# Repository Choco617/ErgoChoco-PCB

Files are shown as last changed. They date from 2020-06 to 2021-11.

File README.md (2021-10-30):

# ErgoChoco-PCB
 My first PCB - a de-split split layout taking my favorite design details from the Corne, Kyria, Absolem, and others.

## The name
 I'm an engineer, and true to form I'm bad at naming things. I'd heard the ErgoDox was designed by a user named Dox, and my handle is Choco617, so: ErgoChoco.
 
## Layout explanation:
I love my Corne, but I quickly found that I always orient the halves the same way, making the actual separation and the TRRS cable more of a nuisance, much as I love the concept. So I experimented with angles and settled on 30°. I had also always wondered if I would like more columnar stagger: the Corne seems pretty conservative on that. So after reading the Kyria design log, I took the same approach, made some measurements of my own fingers’ natural resting positions, and discovered they were negligibly different from the Kyria’s, so I lifted those columnar stagger dimensions wholesale. I love the look of the 1.5U thumb keys on the Corne, but I admit it’s always been annoying for keycap compatibility that they prevent me from just getting a Planck set, so I replaced the 1.5U keys with 1U. I set the hands just far enough apart to fit a Pro Micro between them. A cardboard prototype with leftover switches/caps stuffed into it confirmed that was a comfy layout for me (and the all-1U thumb arcs don’t look as bad as I worried they would).

## Design Priorities:

### PCB
- Kailh hotswap sockets (direct soldering not supported: I'm the only intended user, so I can do what I want :P)
- In-switch LED (with Holtites so that it doesn't defeat the purpose of switch hotswap)
- South-facing switches (I like seeing the LEDs right up front)
- Pro Micro. I originally designed this with an onboard MCU, then decided I would rather keep all the complicated stuff on a Pro Micro to keep the PCB simpler/cheaper and allow me to replace the controller if something awful happened. Also, Pro Micro instead of Elite-C just because I already have micro-USB cables. The Pro Micro is socketed anyway, so I can always change later if I feel like it.
- SMD all the things (mostly diodes/resistors). I wanted to see if I could actually solder all of it myself, and I like the idea of keeping everything as small as possible, and technically minimizing EMI.
- Ground plane everywhere. My original Contra was very prone to ESD shocks, so in the original onboard-MCU version of this PCB, I had an ESD protection circuit with a PRTR5V0U2X. Now with a Pro Micro design, the best I can do (I think) is extensive ground planes and connecting the mounting holes to them so the PCB is grounded to the stainless steel case. I'm a mechanical engineer, not an electrical engineer, so I hope this is sufficient.
- Breakout pads for GND/+5V/F4 data pin to allow RGB underglow (inspired by the Contra). Not sure where I would physically fit an RGB strip, since I intentionally designed no gap under the PCB, but it seemed silly not to include this while I was designing the PCB, since I had the pin available.

### Case (dedicated repo: [https://github.com/Choco617/ErgoChoco-case](https://github.com/Choco617/ErgoChoco-case))
- Stainless sandwich/skeleton case. Top and bottom plates have a perimeter of 8mm aluminum standoffs around the edges of the PCB. I've used this in previous boards, and I love the look.
- Bottom plate mechanically supports hotswap sockets from behind. It annoys me that switch-swapping in my sandwich-case Corne requires me to disassemble everything so I can hold the sockets firm when I insert the new switches, so this case is designed so that the bottom plate (through a layer of non-conductive gasket) contacts the sockets. The PCB is bolted to the bottom plate to keep this secure.
- Minimal height. Without resorting to low-profile switches, I want to keep the plate height as low as possible, mainly for aesthetics and comfort reasons, but also because it's mechanically necessary in order to let the bottom plate contact the backs of the hotswap sockets.
- Pro Micro installation on PCB: to minimize height but still keep the Pro Micro under the plate (I don't like them exposed like on the Corne), the PCB has a U-shaped relief at the Pro Micro footprint. The Pro Micro is installed component-side down on the top of the PCB so the USB port hangs down into that relief.
- Case structure as a result of these choices: PCB is bolted to the top of the bottom plate, with a gasket layer (just vaguely compressible rubbery drawer liner, nothing fancy) in between for electrical insulation, then standoffs are bolted to the top of the bottom plate around the PCB, then the top plate is bolted to the standoffs, then switches are inserted.

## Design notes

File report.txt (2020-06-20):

Info: Checking netlist symbol footprint “R6:/5F0DCCB4:Resistor_SMD:R_0805_2012Metric”.
Info: Checking netlist symbol footprint “MX41:/5F185EF9:Choco617_parts:Kailh_socket_MX_PCBmount_LED_1U”.
Info: Checking netlist symbol footprint “MX42:/5F185F0C:Choco617_parts:Kailh_socket_MX_PCBmount_LED_1U”.
Info: Checking netlist symbol footprint “NPNR1:/5F5CF76A:Resistor_SMD:R_0805_2012Metric”.
Info: Checking netlist symbol footprint “Q1:/5F5CD88C:Package_TO_SOT_SMD:SOT-223”.
Info: Checking netlist symbol footprint “R1:/5F0CFD20:Resistor_SMD:R_0805_2012Metric”.
Info: Checking netlist symbol footprint “R2:/5F0D5418:Resistor_SMD:R_0805_2012Metric”.
Info: Checking netlist symbol footprint “R3:/5F0D6D67:Resistor_SMD:R_0805_2012Metric”.
Info: Checking netlist symbol footprint “R4:/5F0D842C:Resistor_SMD:R_0805_2012Metric”.
Info: Checking netlist symbol footprint “R5:/5F0DB2B4:Resistor_SMD:R_0805_2012Metric”.
Info: Checking netlist symbol footprint “MX40:/5F185EE6:Choco617_parts:Kailh_socket_MX_PCBmount_LED_1U”.
Info: Checking netlist symbol footprint “R7:/5F0DE3D1:Resistor_SMD:R_0805_2012Metric”.
Info: Checking netlist symbol footprint “R8:/5F0E0A19:Resistor_SMD:R_0805_2012Metric”.
Info: Checking netlist symbol footprint “R9:/5F0E23BF:Resistor_SMD:R_0805_2012Metric”.
Info: Checking netlist symbol footprint “R10:/5F0E38CD:Resistor_SMD:R_0805_2012Metric”.
Info: Checking netlist symbol footprint “R11:/5F0E53BC:Resistor_SMD:R_0805_2012Metric”.
Info: Checking netlist symbol footprint “R12:/5F0E6AFF:Resistor_SMD:R_0805_2012Metric”.
Info: Checking netlist symbol footprint “R13:/5F13CD72:Resistor_SMD:R_0805_2012Metric”.
Info: Checking netlist symbol footprint “R14:/5F13CD85:Resistor_SMD:R_0805_2012Metric”.
Info: Checking netlist symbol footprint “MX31:/5F163023:Choco617_parts:Kailh_socket_MX_PCBmount_LED_1U”.
Info: Checking netlist symbol footprint “MX23:/5F13CE23:Choco617_parts:Kailh_socket_MX_PCBmount_LED_1U”.
Info: Checking netlist symbol footprint “MX24:/5F13CE36:Choco617_parts:Kailh_socket_MX_PCBmount_LED_1U”.
Info: Checking netlist symbol footprint “MX25:/5F162FB1:Choco617_parts:Kailh_socket_MX_PCBmount_LED_1U”.
Info: Checking netlist symbol footprint “MX26:/5F162FC4:Choco617_parts:Kailh_socket_MX_PCBmount_LED_1U”.
Info: Checking netlist symbol footprint “MX27:/5F162FD7:Choco617_parts:Kailh_socket_MX_PCBmount_LED_1U”.
Info: Checking netlist symbol footprint “MX28:/5F162FEA:Choco617_parts:Kailh_socket_MX_PCBmount_LED_1U”.
Info: Checking netlist symbol footprint “MX29:/5F162FFD:Choco617_parts:Kailh_socket_MX_PCBmount_LED_1U”.
Info: Checking netlist symbol footprint “MX30:/5F163010:Choco617_parts:Kailh_socket_MX_PCBmount_LED_1U”.
Info: Checking netlist symbol footprint “R15:/5F13CD98:Resistor_SMD:R_0805_2012Metric”.
Info: Checking netlist symbol footprint “MX32:/5F163036:Choco617_parts:Kailh_socket_MX_PCBmount_LED_1U”.
Info: Checking netlist symbol footprint “MX33:/5F163049:Choco617_parts:Kailh_socket_MX_PCBmount_LED_1U”.
Info: Checking netlist symbol footprint “MX34:/5F16305C:Choco617_parts:Kailh_socket_MX_PCBmount_LED_1U”.
Info: Checking netlist symbol footprint “MX35:/5F16306F:Choco617_parts:Kailh_socket_MX_PCBmount_LED_1U”.
Info: Checking netlist symbol footprint “MX36:/5F163082:Choco617_parts:Kailh_socket_MX_PCBmount_LED_1U”.
Info: Checking netlist symbol footprint “MX37:/5F185EAD:Choco617_parts:Kailh_socket_MX_PCBmount_LED_1U”.
Info: Checking netlist symbol footprint “MX38:/5F185EC0:Choco617_parts:Kailh_socket_MX_PCBmount_LED_1U”.
Info: Checking netlist symbol footprint “MX39:/5F185ED3:Choco617_parts:Kailh_socket_MX_PCBmount_LED_1U”.
Info: Checking netlist symbol footprint “R42:/5F185F19:Resistor_SMD:R_0805_2012Metric”.
Info: Checking netlist symbol footprint “R34:/5F163069:Resistor_SMD:R_0805_2012Metric”.
Info: Checking netlist symbol footprint “R35:/5F16307C:Resistor_SMD:R_0805_2012Metric”.
Info: Checking netlist symbol footprint “R36:/5F16308F:Resistor_SMD:R_0805_2012Metric”.
Info: Checking netlist symbol footprint “R37:/5F185EBA:Resistor_SMD:R_0805_2012Metric”.
Info: Checking netlist symbol footprint “R38:/5F185ECD:Resistor_SMD:R_0805_2012Metric”.
Info: Checking netlist symbol footprint “R39:/5F185EE0:Resistor_SMD:R_0805_2012Metric”.
Info: Checking netlist symbol footprint “R40:/5F185EF3:Resistor_SMD:R_0805_2012Metric”.
Info: Checking netlist symbol footprint “R41:/5F185F06:Resistor_SMD:R_0805_2012Metric”.
Info: Checking netlist symbol footprint “R33:/5F163056:Resistor_SMD:R_0805_2012Metric”.
Info: Checking netlist symbol footprint “R43:/5EEC55CA:Resistor_SMD:R_0805_2012Metric”.
Info: Checking netlist symbol footprint “R44:/5F5EB1F7:Resistor_SMD:R_0805_2012Metric”.
Info: Checking netlist symbol footprint “R45:/5F601D9F:Resistor_SMD:R_0805_2012Metric”.
Info: Checking netlist symbol footprint “R46:/5EE95709:Resistor_SMD:R_0805_2012Metric”.
Info: Checking netlist symbol footprint “SW1:/5EEBD541:random-keyboard-parts:SKQG-1155865”.
Info: Checking netlist symbol footprint “U1:/5EE90A1B:Package_QFP:TQFP-44_10x10mm_P0.8mm”.
Info: Checking netlist symbol footprint “U2:/5F5EB805:random-keyboard-parts:SOT143B”.
Info: Checking netlist symbol footprint “Y1:/5EEB2728:Crystal:Crystal_SMD_3225-4Pin_3.2x2.5mm”.
Info: Checking netlist symbol footprint “R24:/5F13CE43:Resistor_SMD:R_0805_2012Metric”.
Info: Checking netlist symbol footprint “R16:/5F13CDAB:Resistor_SMD:R_0805_2012Metric”.
Info: Checking netlist symbol footprint “R17:/5F13CDBE:Resistor_SMD:R_0805_2012Metric”.
Info: Checking netlist symbol footprint “R18:/5F13CDD1:Resistor_SMD:R_0805_2012Metric”.
Info: Checking netlist symbol footprint “R19:/5F13CDE4:Resistor_SMD:R_0805_2012Metric”.
Info: Checking netlist symbol footprint “R20:/5F13CDF7:Resistor_SMD:R_0805_2012Metric”.
Info: Checking netlist symbol footprint “R21:/5F13CE0A:Resistor_SMD:R_0805_2012Metric”.
Info: Checking netlist symbol footprint “R22:/5F13CE1D:Resistor_SMD:R_0805_2012Metric”.
Info: Checking netlist symbol footprint “R23:/5F13CE30:Resistor_SMD:R_0805_2012Metric”.
Info: Checking netlist symbol footprint “C2:/5EE9CDB9:Capacitor_SMD:C_0805_2012Metric”.
Info: Checking netlist symbol footprint “R25:/5F162FBE:Resistor_SMD:R_0805_2012Metric”.
Info: Checking netlist symbol footprint “R26:/5F162FD1:Resistor_SMD:R_0805_2012Metric”.
Info: Checking netlist symbol footprint “R27:/5F162FE4:Resistor_SMD:R_0805_2012Metric”.
Info: Checking netlist symbol footprint “R28:/5F162FF7:Resistor_SMD:R_0805_2012Metric”.
Info: Checking netlist symbol footprint “R29:/5F16300A:Resistor_SMD:R_0805_2012Metric”.
Info: Checking netlist symbol footprint “R30:/5F16301D:Resistor_SMD:R_0805_2012Metric”.
Info: Checking netlist symbol footprint “R31:/5F163030:Resistor_SMD:R_0805_2012Metric”.
Info: Checking netlist symbol footprint “R32:/5F163043:Resistor_SMD:R_0805_2012Metric”.
Info: Checking netlist symbol footprint “D21:/5F13CE03:Diode_SMD:D_SOD-123”.
Info: Checking netlist symbol footprint “D13:/5F13CD6B:Diode_SMD:D_SOD-123”.
Info: Checking netlist symbol footprint “D14:/5F13CD7E:Diode_SMD:D_SOD-123”.
Info: Checking netlist symbol footprint “D15:/5F13CD91:Diode_SMD:D_SOD-123”.
Info: Checking netlist symbol footprint “D16:/5F13CDA4:Diode_SMD:D_SOD-123”.
Info: Checking netlist symbol footprint “D17:/5F13CDB7:Diode_SMD:D_SOD-123”.
Info: Checking netlist symbol footprint “D18:/5F13CDCA:Diode_SMD:D_SOD-123”.
Info: Checking netlist symbol footprint “D19:/5F13CDDD:Diode_SMD:D_SOD-123”.
Info: Checking netlist symbol footprint “D20:/5F13CDF0:Diode_SMD:D_SOD-123”.
Info: Checking netlist symbol footprint “D12:/5F0E6AF8:Diode_SMD:D_SOD-123”.
Info: Checking netlist symbol footprint “D22:/5F13CE16:Diode_SMD:D_SOD-123”.
Info: Checking netlist symbol footprint “D23:/5F13CE29:Diode_SMD:D_SOD-123”.
Info: Checking netlist symbol footprint “D24:/5F13CE3C:Diode_SMD:D_SOD-123”.
Info: Checking netlist symbol footprint “D25:/5F162FB7:Diode_SMD:D_SOD-123”.
Info: Checking netlist symbol footprint “D26:/5F162FCA:Diode_SMD:D_SOD-123”.
Info: Checking netlist symbol footprint “D27:/5F162FDD:Diode_SMD:D_SOD-123”.
Info: Checking netlist symbol footprint “D28:/5F162FF0:Diode_SMD:D_SOD-123”.
Info: Checking netlist symbol footprint “D29:/5F163003:Diode_SMD:D_SOD-123”.
Info: Checking netlist symbol footprint “D3:/5F0D6D60:Diode_SMD:D_SOD-123”.
Info: Checking netlist symbol footprint “C1:/5EE99A4F:Capacitor_SMD:C_0805_2012Metric”.
Info: Checking netlist symbol footprint “C3:/5EE9DE37:Capacitor_SMD:C_0805_2012Metric”.
Info: Checking netlist symbol footprint “C4:/5EE9E32A:Capacitor_SMD:C_0805_2012Metric”.
Info: Checking netlist symbol footprint “C5:/5EE9E68C:Capacitor_SMD:C_0805_2012Metric”.
Info: Checking netlist symbol footprint “C6:/5EEB6068:Capacitor_SMD:C_0805_2012Metric”.
Info: Checking netlist symbol footprint “C7:/5EEB747F:Capacitor_SMD:C_0805_2012Metric”.
Info: Checking netlist symbol footprint “D1:/5F0CCCEC:Diode_SMD:D_SOD-123”.
Info: Checking netlist symbol footprint “D2:/5F0D5411:Diode_SMD:D_SOD-123”.
Info: Checking netlist symbol footprint “MX21:/5F13CDFD:Choco617_parts:Kailh_socket_MX_PCBmount_LED_1U”.
Info: Checking netlist symbol footprint “D4:/5F0D8425:Diode_SMD:D_SOD-123”.
Info: Checking netlist symbol footprint “D5:/5F0DB2AD:Diode_SMD:D_SOD-123”.
Info: Checking netlist symbol footprint “D6:/5F0DCCAD:Diode_SMD:D_SOD-123”.
Info: Checking netlist symbol footprint “D7:/5F0DE3CA:Diode_SMD:D_SOD-123”.
Info: Checking netlist symbol footprint “D8:/5F0E0A12:Diode_SMD:D_SOD-123”.
Info: Checking netlist symbol footprint “D9:/5F0E23B8:Diode_SMD:D_SOD-123”.
Info: Checking netlist symbol footprint “D10:/5F0E38C6:Diode_SMD:D_SOD-123”.
Info: Checking netlist symbol footprint “D11:/5F0E53B5:Diode_SMD:D_SOD-123”.
Info: Checking netlist symbol footprint “MX13:/5F13CD65:Choco617_parts:Kailh_socket_MX_PCBmount_LED_1U”.
Info: Checking netlist symbol footprint “MX5:/5F0DB2A7:Choco617_parts:Kailh_socket_MX_PCBmount_LED_1U”.
Info: Checking netlist symbol footprint “MX6:/5F0DCCA7:Choco617_parts:Kailh_socket_MX_PCBmount_LED_1U”.
Info: Checking netlist symbol footprint “MX7:/5F0DE3C4:Choco617_parts:Kailh_socket_MX_PCBmount_LED_1U”.
Info: Checking netlist symbol footprint “MX8:/5F0E0A0C:Choco617_parts:Kailh_socket_MX_PCBmount_LED_1U”.
Info: Checking netlist symbol footprint “MX9:/5F0E23B2:Choco617_parts:Kailh_socket_MX_PCBmount_LED_1U”.
Info: Checking netlist symbol footprint “MX10:/5F0E38C0:Choco617_parts:Kailh_socket_MX_PCBmount_LED_1U”.
Info: Checking netlist symbol footprint “MX11:/5F0E53AF:Choco617_parts:Kailh_socket_MX_PCBmount_LED_1U”.
Info: Checking netlist symbol footprint “MX12:/5F0E6AF2:Choco617_parts:Kailh_socket_MX_PCBmount_LED_1U”.
Info: Checking netlist symbol footprint “D31:/5F163029:Diode_SMD:D_SOD-123”.
Info: Checking netlist symbol footprint “MX14:/5F13CD78:Choco617_parts:Kailh_socket_MX_PCBmount_LED_1U”.
Info: Checking netlist symbol footprint “MX15:/5F13CD8B:Choco617_parts:Kailh_socket_MX_PCBmount_LED_1U”.
Info: Checking netlist symbol footprint “MX16:/5F13CD9E:Choco617_parts:Kailh_socket_MX_PCBmount_LED_1U”.
Info: Checking netlist symbol footprint “MX17:/5F13CDB1:Choco617_parts:Kailh_socket_MX_PCBmount_LED_1U”.
Info: Checking netlist symbol footprint “MX18:/5F13CDC4:Choco617_parts:Kailh_socket_MX_PCBmount_LED_1U”.
Info: Checking netlist symbol footprint “MX19:/5F13CDD7:Choco617_parts:Kailh_socket_MX_PCBmount_LED_1U”.
Info: Checking netlist symbol footprint “MX20:/5F13CDEA:Choco617_parts:Kailh_socket_MX_PCBmount_LED_1U”.
Info: Checking netlist symbol footprint “MX22:/5F13CE10:Choco617_parts:Kailh_socket_MX_PCBmount_LED_1U”.
Info: Checking netlist symbol footprint “MX3:/5F0D6D5A:Choco617_parts:Kailh_socket_MX_PCBmount_LED_1U”.
Info: Checking netlist symbol footprint “D30:/5F163016:Diode_SMD:D_SOD-123”.
Info: Checking netlist symbol footprint “D32:/5F16303C:Diode_SMD:D_SOD-123”.
Info: Checking netlist symbol footprint “D33:/5F16304F:Diode_SMD:D_SOD-123”.
Info: Checking netlist symbol footprint “D34:/5F163062:Diode_SMD:D_SOD-123”.
Info: Checking netlist symbol footprint “D35:/5F163075:Diode_SMD:D_SOD-123”.
Info: Checking netlist symbol footprint “D36:/5F163088:Diode_SMD:D_SOD-123”.
Info: Checking netlist symbol footprint “D37:/5F185EB3:Diode_SMD:D_SOD-123”.
Info: Checking netlist symbol footprint “D38:/5F185EC6:Diode_SMD:D_SOD-123”.
Info: Checking netlist symbol footprint “D39:/5F185ED9:Diode_SMD:D_SOD-123”.
Info: Checking netlist symbol footprint “D40:/5F185EEC:Diode_SMD:D_SOD-123”.
Info: Checking netlist symbol footprint “D41:/5F185EFF:Diode_SMD:D_SOD-123”.
Info: Checking netlist symbol footprint “D42:/5F185F12:Diode_SMD:D_SOD-123”.
Info: Checking netlist symbol footprint “F1:/5EED8839:Fuse:Fuse_1206_3216Metric”.
Info: Checking netlist symbol footprint “J1:/5EED7A0C:Choco617_parts:CUI_UJ2-MIBH2-4-SMT”.
Info: Checking netlist symbol footprint “MX1:/5F0CAF10:Choco617_parts:Kailh_socket_MX_PCBmount_LED_1U”.
Info: Checking netlist symbol footprint “MX2:/5F0D540B:Choco617_parts:Kailh_socket_MX_PCBmount_LED_1U”.
Info: Checking netlist symbol footprint “MX4:/5F0D841F:Choco617_parts:Kailh_socket_MX_PCBmount_LED_1U”.
Error: Symbol J1 pad 6 not found in footprint Choco617_parts:CUI_UJ2-MIBH2-4-SMT.

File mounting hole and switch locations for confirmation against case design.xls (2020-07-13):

mounting hole locations | X | Y | Mirror-X
1 | 65.43125 | 58 | 231.43125
2 | 120.43125 | 58 | 176.43125
3 | 176.43125 | 58 | 120.43125
4 | 231.43125 | 58 | 65.43125
5 | 20.4125 | 81.7 | 276.45
6 | 276.45 | 81.7 | 20.4125
7 | 86.43125 | 111 | 210.43125
8 | 210.43125 | 111 | 86.43125
9 | 127.43125 | 130.5 | 169.43125
10 | 169.43125 | 130.5 | 127.43125
switch locations |  |  | Mirror-X | Diff against real mirror | SW measurement |  | diff
1 | 39.34 | 63.99 | 257.5225 | 0.0025 | 39.34 | 63.99 | 0 | 0
2 | 57.69 | 68.9 | 239.1725 | 0.0025 | 57.69 | 68.91 | 0 | 0.01
3 | 79.15 | 62.23 | 217.7125 | 0.0025 | 79.15 | 62.23 | 0 | 0
4 | 99.05 | 61.35 | 197.8125 | 0.0025 | 99.06 | 61.36 | 0.01 | 0.01
5 | 115.72 | 72.55 | 181.1425 | 0.0025 | 115.73 | 72.55 | 0.01 | 0
6 | 133.43 | 79.88 | 163.4325 | 0.0025 | 133.43 | 79.88 | 0 | 0
7 | 163.43 | 79.88 | 133.4325 |  | 163.43 | 79.88 | 0 | 0
8 | 181.14 | 72.55 | 115.7225 |  | 181.14 | 72.55 | 0 | 0
9 | 197.81 | 61.35 | 99.0525 |  | 197.81 | 61.34 | 0 | -0.01
10 | 217.71 | 62.23 | 79.1525 |  | 217.71 | 62.23 | 0 | 0
11 | 239.17 | 68.9 | 57.6925 |  | 239.17 | 68.91 | 0 | 0.01
12 | 257.52 | 63.99 | 39.3425 |  | 257.52 | 63.99 | 0 | 0
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

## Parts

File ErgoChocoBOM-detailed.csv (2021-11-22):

Id | Designator | Package | Quantity | Designation | Description | Supplier and ref
1 | REF**,REF**,REF**,REF**,REF**,REF**,REF**,REF** | PTH_2.2_4 | 8 | PTH_2.2_4 | Through-holes for mounting PCB | N/A
2 | Q1 | SOT-23-3 | 1 | Q_NPN_BCE | MOSFET for LEDs | Digi-Key AO3416
3 | SW1 | SKQG-1155865 | 1 | SW_Push | Reset switch | Digi-Key RS-187R05A2-DS
4 | MX2,MX1,MX40,MX15,MX3,MX4,MX5,MX6,MX7,MX8,MX9,MX10,MX11,MX12,MX13,MX14,MX16,MX17,MX18,MX19,MX20,MX21,MX22,MX23,MX24,MX25,MX26,MX27,MX28,MX29,MX30,MX31,MX32,MX33,MX34,MX35,MX36,MX37,MX38,MX39,MX41,MX42 | Kailh_socket_MX_PCBmount_LED_1U | 42 | MX-LED | Keyswitches
5 | D42,D41,D40,D39,D38,D37,D36,D35,D34,D33,D32,D31,D30,D29,D28,D27,D26,D25,D24,D23,D22,D21,D20,D19,D18,D17,D16,D15,D14,D13,D12,D11,D10,D9,D8,D7,D6,D5,D4,D3,D2,D1 | D_SOD-123-HandSolder | 42 | SOD-123 | Diodes | Digi-Key 1N4148WQ-7-F
6 | U1 | ArduinoProMicro | 1 | ProMicro | Pro Micro | Keebio
7 | NPNR1 | R_0805_2012Metric | 1 | 1.5k | 1.5k overall resistor for LEDs | Digi-Key CRGCQ0805F1K5
8 | R1,R2,R3,R4,R5,R6,R7,R8,R9,R10,R11,R12,R13,R14,R15,R16,R17,R18,R19,R20,R21,R22,R23,R24,R25,R26,R27,R28,R29,R30,R31,R32,R33,R34,R35,R36,R37,R38,R39,R40,R41,R42 | R_0805_2012Metric | 42 | 470 | 470 resistors for each LED | Digi-Key CRGCQ0805F470R
9 | J1 | PinHeader_1x03_P2.54mm_Vertical | 1 | Conn_01x03 | Header connections for unused Pro Micro pins | N/A

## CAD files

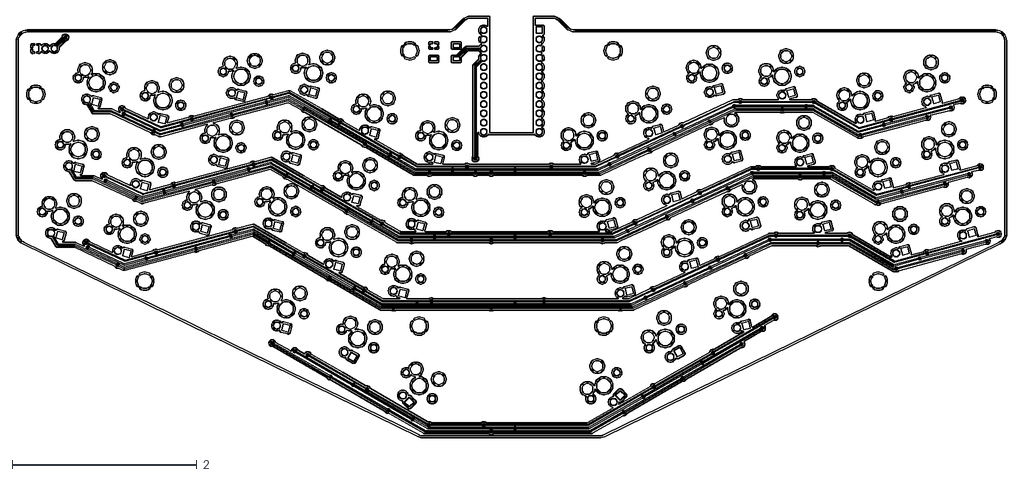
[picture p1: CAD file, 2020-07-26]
ErgoChoco-F_Cu.dxf
10.7 x 4.56

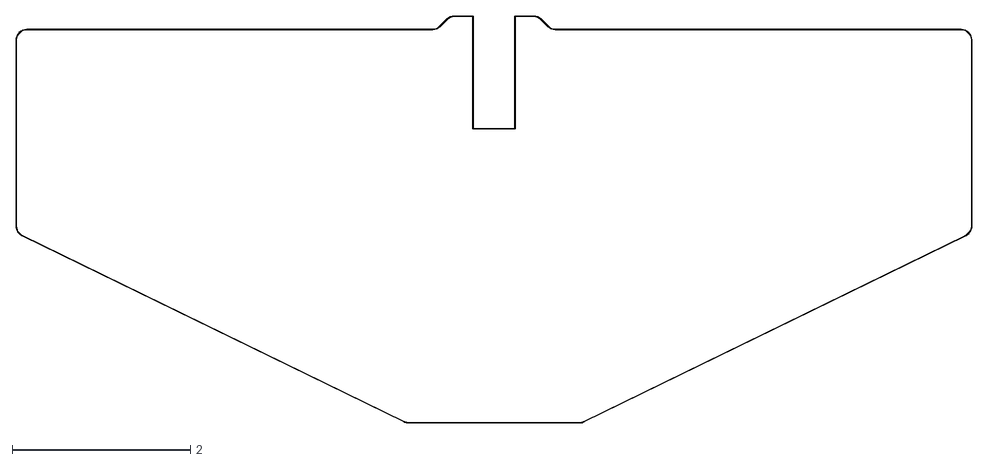
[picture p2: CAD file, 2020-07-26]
ErgoChoco-Edge_Cuts.dxf
10.7 x 4.56

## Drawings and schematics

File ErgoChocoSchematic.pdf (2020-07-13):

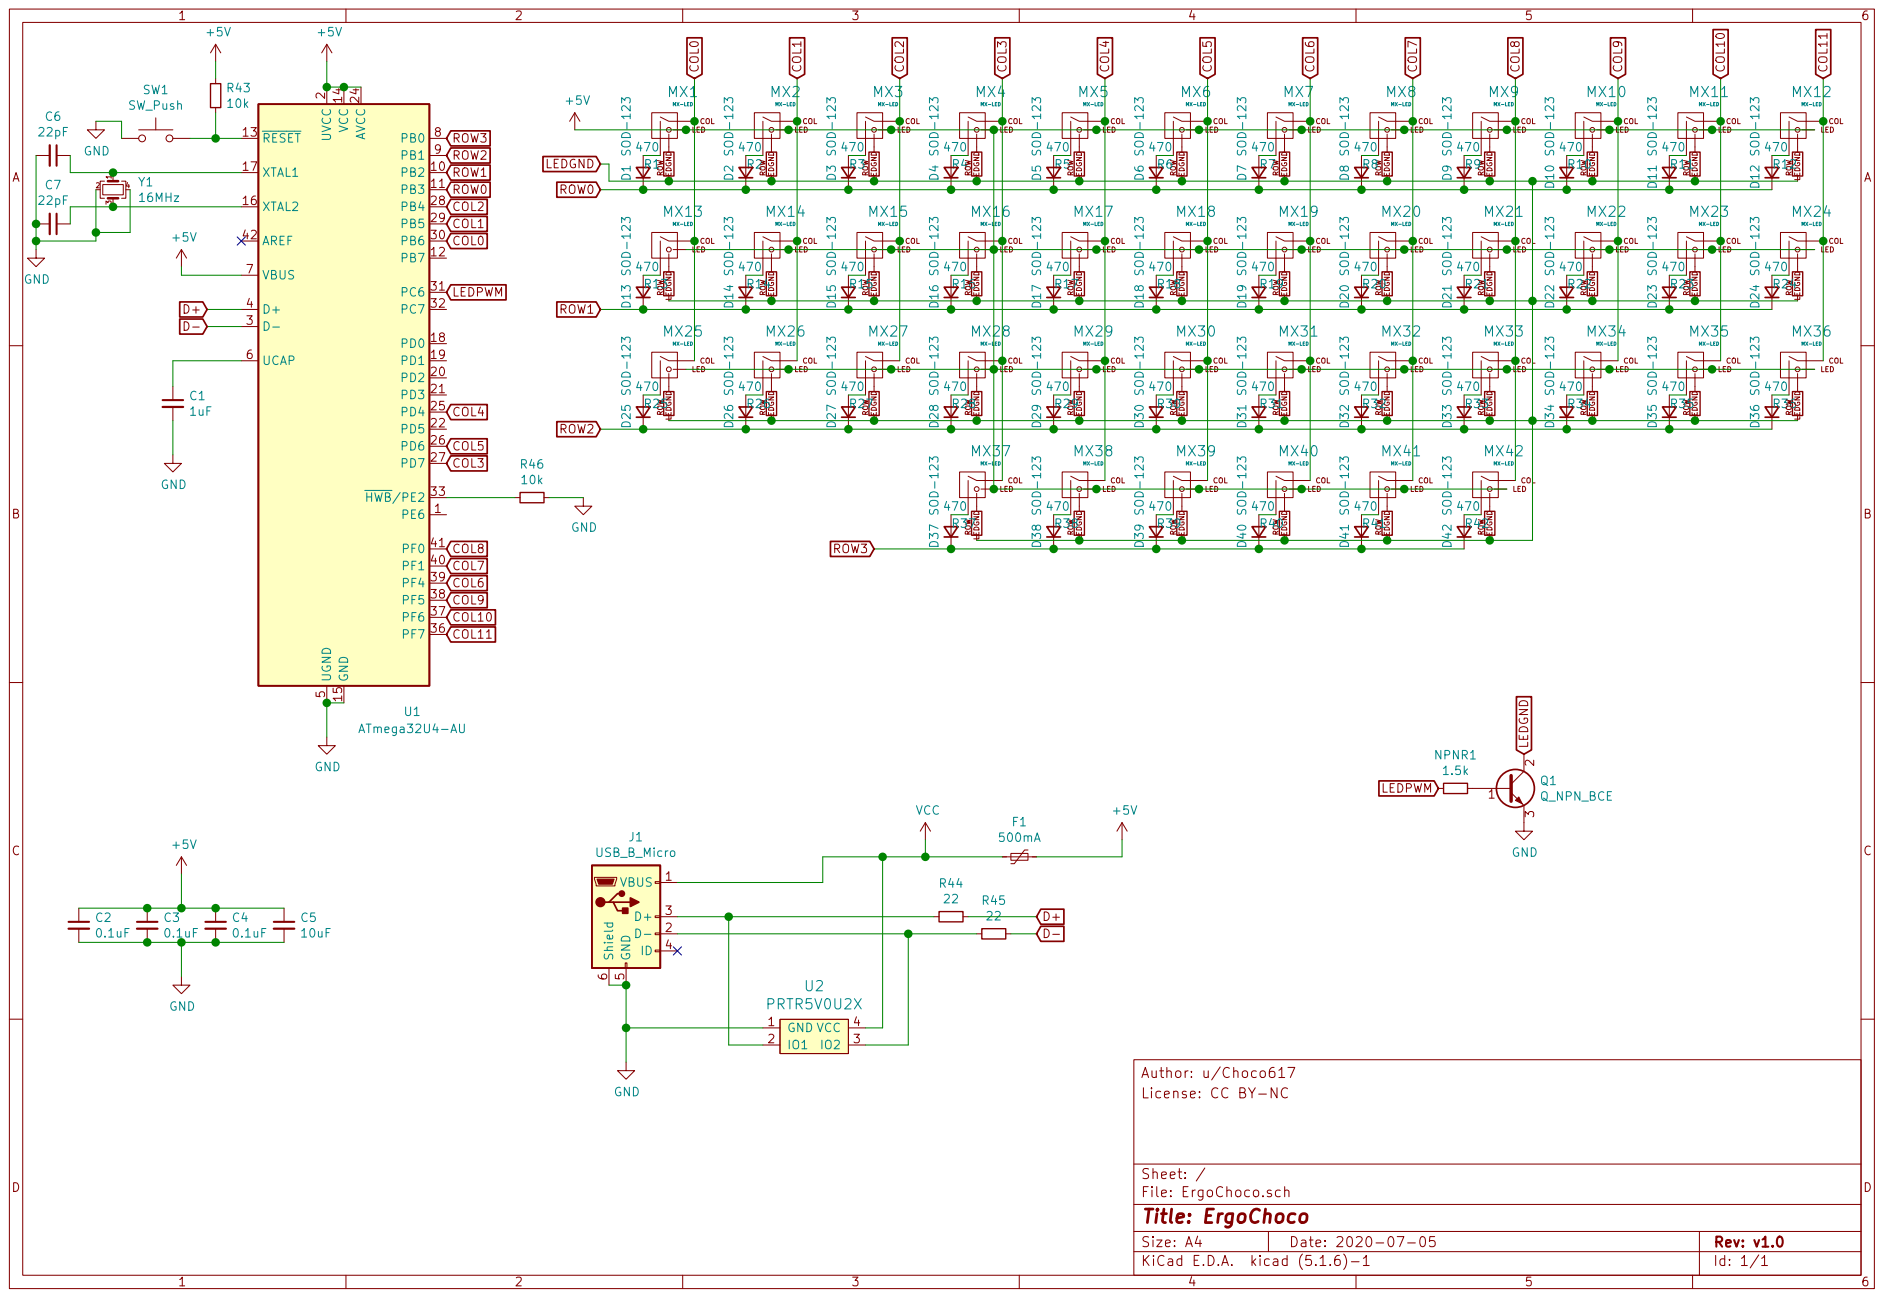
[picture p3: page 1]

2 PD2 20 PD3 21 PD5 22 AVCC 24 PD4 25 PD6 26 PD7 27 PB4 28 PB5 29 D- 3 PB6 30 PC6 31 PC7 32 HWB/PE2 33 PF7 36 PF6 37 PF5 38 PF4 39 D+ 4 PF1 40 PF0 41 AREF 42 UGND

MX-LED | LED ROW LEDGND MX21 COL | D12 SOD-123 R7

LED ROW LEDGND MX33 COL

22 GND 1

Author: u/Choco617
File: ErgoChoco.sch Sheet: / License: CC BY-NC

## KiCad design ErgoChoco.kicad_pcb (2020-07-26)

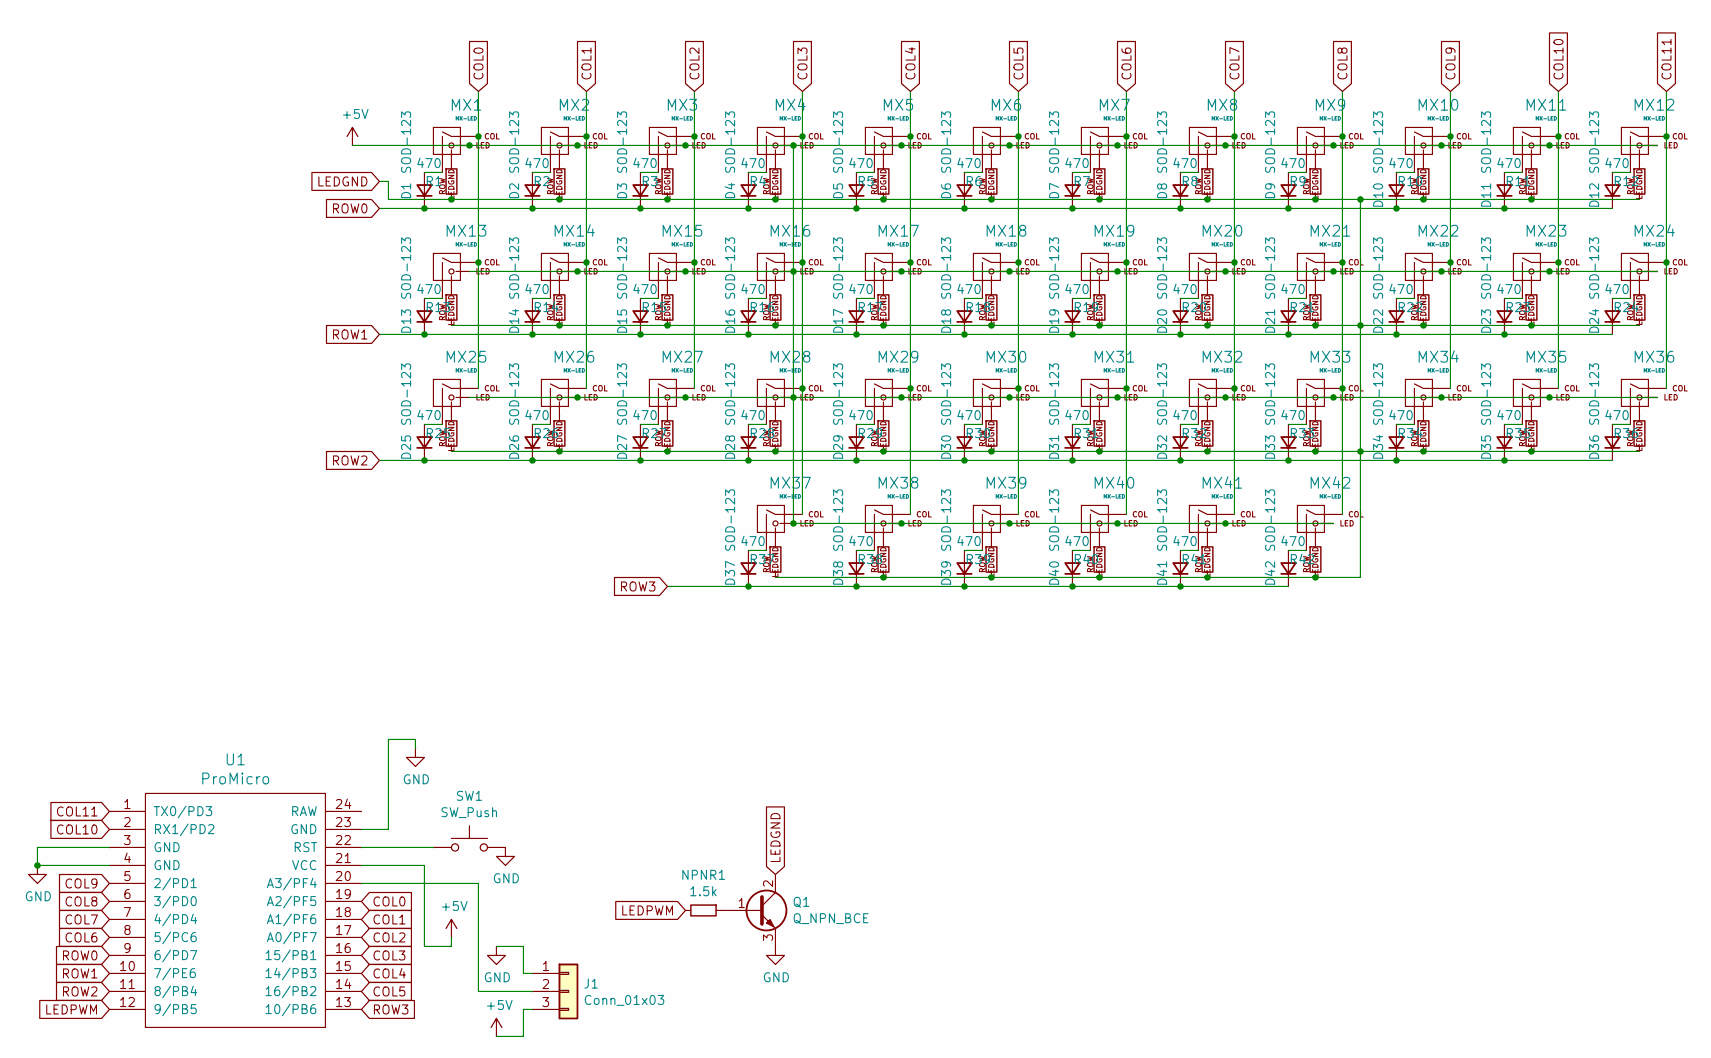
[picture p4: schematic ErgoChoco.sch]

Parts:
D1, D2, D3, D4, D5, D6, D7, D8, D9, D10, D11, D12, D13, D14, D15, D16, D17, D18, D19, D20, D21, D22, D23, D24, D25, D26, D27, D28, D29, D30, D31, D32, D33, D34, D35, D36, D37, D38, D39, D40, D41, D42: SOD-123; D_SOD-123-HandSolder
J1: Conn_01x03; PinHeader_1x03_P2.54mm_Vertical
MX1, MX2, MX3, MX4, MX5, MX6, MX7, MX8, MX9, MX10, MX11, MX12, MX13, MX14, MX15, MX16, MX17, MX18, MX19, MX20, MX21, MX22, MX23, MX24, MX25, MX26, MX27, MX28, MX29, MX30, MX31, MX32, MX33, MX34, MX35, MX36, MX37, MX38, MX39, MX40, MX41, MX42: MX-LED; Kailh_socket_MX_PCBmount_LED_1U
NPNR1: 1.5k; R_0805_2012Metric
Q1: Q_NPN_BCE; SOT-23-3
R1, R2, R3, R4, R5, R6, R7, R8, R9, R10, R11, R12, R13, R14, R15, R16, R17, R18, R19, R20, R21, R22, R23, R24, R25, R26, R27, R28, R29, R30, R31, R32, R33, R34, R35, R36, R37, R38, R39, R40, R41, R42: 470; R_0805_2012Metric
SW1: SW_Push; SKQG-1155865
U1: ProMicro; ArduinoProMicro

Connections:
+5V: J1.3, MX1.3 (LED), MX2.3 (LED), MX3.3 (LED), MX4.3 (LED), MX5.3 (LED), MX6.3 (LED), MX7.3 (LED), MX8.3 (LED), MX9.3 (LED), MX10.3 (LED), MX11.3 (LED), MX12.3 (LED), MX13.3 (LED), MX14.3 (LED), MX15.3 (LED), MX16.3 (LED), MX17.3 (LED), MX18.3 (LED), MX19.3 (LED), MX20.3 (LED), MX21.3 (LED), MX22.3 (LED), MX23.3 (LED), MX24.3 (LED), MX25.3 (LED), MX26.3 (LED), MX27.3 (LED), MX28.3 (LED), MX29.3 (LED), MX30.3 (LED), MX31.3 (LED), MX32.3 (LED), MX33.3 (LED), MX34.3 (LED), MX35.3 (LED), MX36.3 (LED), MX37.3 (LED), MX38.3 (LED), MX39.3 (LED), MX40.3 (LED), MX41.3 (LED), MX42.3 (LED), U1.21 (VCC)
COL0: MX1.1 (COL), MX13.1 (COL), MX25.1 (COL), U1.19 (A2/PF5)
COL1: MX2.1 (COL), MX14.1 (COL), MX26.1 (COL), U1.18 (A1/PF6)
COL2: MX3.1 (COL), MX15.1 (COL), MX27.1 (COL), U1.17 (A0/PF7)
COL3: MX4.1 (COL), MX16.1 (COL), MX28.1 (COL), MX37.1 (COL), U1.16 (15/PB1)
COL4: MX5.1 (COL), MX17.1 (COL), MX29.1 (COL), MX38.1 (COL), U1.15 (14/PB3)
COL5: MX6.1 (COL), MX18.1 (COL), MX30.1 (COL), MX39.1 (COL), U1.14 (16/PB2)
COL6: MX7.1 (COL), MX19.1 (COL), MX31.1 (COL), MX40.1 (COL), U1.8 (5/PC6)
COL7: MX8.1 (COL), MX20.1 (COL), MX32.1 (COL), MX41.1 (COL), U1.7 (4/PD4)
COL8: MX9.1 (COL), MX21.1 (COL), MX33.1 (COL), MX42.1 (COL), U1.6 (3/PD0)
COL9: MX10.1 (COL), MX22.1 (COL), MX34.1 (COL), U1.5 (2/PD1)
COL10: MX11.1 (COL), MX23.1 (COL), MX35.1 (COL), U1.2 (RX1/PD2)
COL11: MX12.1 (COL), MX24.1 (COL), MX36.1 (COL), U1.1 (TX0/PD3)
GND: J1.1, Q1.3 (E), SW1.2, U1.3 (GND), U1.4 (GND), U1.23 (GND)
LEDGND: Q1.2 (C), R1.2, R2.2, R3.2, R4.2, R5.2, R6.2, R7.2, R8.2, R9.2, R10.2, R11.2, R12.2, R13.2, R14.2, R15.2, R16.2, R17.2, R18.2, R19.2, R20.2, R21.2, R22.2, R23.2, R24.2, R25.2, R26.2, R27.2, R28.2, R29.2, R30.2, R31.2, R32.2, R33.2, R34.2, R35.2, R36.2, R37.2, R38.2, R39.2, R40.2, R41.2, R42.2
LEDPWM: NPNR1.2, U1.12 (9/PB5)
unnamed: D1.2 (A), MX1.2 (ROW)
unnamed: D2.2 (A), MX2.2 (ROW)
unnamed: D3.2 (A), MX3.2 (ROW)
unnamed: D4.2 (A), MX4.2 (ROW)
unnamed: D5.2 (A), MX5.2 (ROW)
unnamed: D6.2 (A), MX6.2 (ROW)
unnamed: D7.2 (A), MX7.2 (ROW)
unnamed: D8.2 (A), MX8.2 (ROW)
unnamed: D9.2 (A), MX9.2 (ROW)
unnamed: D10.2 (A), MX10.2 (ROW)
unnamed: D11.2 (A), MX11.2 (ROW)
unnamed: D12.2 (A), MX12.2 (ROW)
unnamed: D13.2 (A), MX13.2 (ROW)
unnamed: D14.2 (A), MX14.2 (ROW)
unnamed: D15.2 (A), MX15.2 (ROW)
unnamed: D16.2 (A), MX16.2 (ROW)
unnamed: D17.2 (A), MX17.2 (ROW)
unnamed: D18.2 (A), MX18.2 (ROW)
unnamed: D19.2 (A), MX19.2 (ROW)
unnamed: D20.2 (A), MX20.2 (ROW)
unnamed: D21.2 (A), MX21.2 (ROW)
unnamed: D22.2 (A), MX22.2 (ROW)
unnamed: D23.2 (A), MX23.2 (ROW)
unnamed: D24.2 (A), MX24.2 (ROW)
unnamed: D25.2 (A), MX25.2 (ROW)
unnamed: D26.2 (A), MX26.2 (ROW)
unnamed: D27.2 (A), MX27.2 (ROW)
unnamed: D28.2 (A), MX28.2 (ROW)
unnamed: D29.2 (A), MX29.2 (ROW)
unnamed: D30.2 (A), MX30.2 (ROW)
unnamed: D31.2 (A), MX31.2 (ROW)
unnamed: D32.2 (A), MX32.2 (ROW)
unnamed: D33.2 (A), MX33.2 (ROW)
unnamed: D34.2 (A), MX34.2 (ROW)
unnamed: D35.2 (A), MX35.2 (ROW)
unnamed: D36.2 (A), MX36.2 (ROW)
unnamed: D37.2 (A), MX37.2 (ROW)
unnamed: D38.2 (A), MX38.2 (ROW)
unnamed: D39.2 (A), MX39.2 (ROW)
unnamed: D40.2 (A), MX40.2 (ROW)
unnamed: D41.2 (A), MX41.2 (ROW)
unnamed: D42.2 (A), MX42.2 (ROW)
unnamed: J1.2, U1.20 (A3/PF4)
unnamed: MX1.4 (LEDGND), R1.1
unnamed: MX2.4 (LEDGND), R2.1
unnamed: MX3.4 (LEDGND), R3.1
unnamed: MX4.4 (LEDGND), R4.1
unnamed: MX5.4 (LEDGND), R5.1
unnamed: MX6.4 (LEDGND), R6.1
unnamed: MX7.4 (LEDGND), R7.1
unnamed: MX8.4 (LEDGND), R8.1
unnamed: MX9.4 (LEDGND), R9.1
unnamed: MX10.4 (LEDGND), R10.1
unnamed: MX11.4 (LEDGND), R11.1
unnamed: MX12.4 (LEDGND), R12.1
unnamed: MX13.4 (LEDGND), R13.1
unnamed: MX14.4 (LEDGND), R14.1
unnamed: MX15.4 (LEDGND), R15.1
unnamed: MX16.4 (LEDGND), R16.1
unnamed: MX17.4 (LEDGND), R17.1
unnamed: MX18.4 (LEDGND), R18.1
unnamed: MX19.4 (LEDGND), R19.1
unnamed: MX20.4 (LEDGND), R20.1
unnamed: MX21.4 (LEDGND), R21.1
unnamed: MX22.4 (LEDGND), R22.1
unnamed: MX23.4 (LEDGND), R23.1
unnamed: MX24.4 (LEDGND), R24.1
unnamed: MX25.4 (LEDGND), R25.1
unnamed: MX26.4 (LEDGND), R26.1
unnamed: MX27.4 (LEDGND), R27.1
unnamed: MX28.4 (LEDGND), R28.1
unnamed: MX29.4 (LEDGND), R29.1
unnamed: MX30.4 (LEDGND), R30.1
unnamed: MX31.4 (LEDGND), R31.1
unnamed: MX32.4 (LEDGND), R32.1
unnamed: MX33.4 (LEDGND), R33.1
unnamed: MX34.4 (LEDGND), R34.1
unnamed: MX35.4 (LEDGND), R35.1
unnamed: MX36.4 (LEDGND), R36.1
unnamed: MX37.4 (LEDGND), R37.1
unnamed: MX38.4 (LEDGND), R38.1
unnamed: MX39.4 (LEDGND), R39.1
unnamed: MX40.4 (LEDGND), R40.1
unnamed: MX41.4 (LEDGND), R41.1
unnamed: MX42.4 (LEDGND), R42.1
unnamed: NPNR1.1, Q1.1 (B)
unnamed: SW1.1, U1.22 (RST)
ROW0: D1.1 (K), D2.1 (K), D3.1 (K), D4.1 (K), D5.1 (K), D6.1 (K), D7.1 (K), D8.1 (K), D9.1 (K), D10.1 (K), D11.1 (K), D12.1 (K), U1.9 (6/PD7)
ROW1: D13.1 (K), D14.1 (K), D15.1 (K), D16.1 (K), D17.1 (K), D18.1 (K), D19.1 (K), D20.1 (K), D21.1 (K), D22.1 (K), D23.1 (K), D24.1 (K), U1.10 (7/PE6)
ROW2: D25.1 (K), D26.1 (K), D27.1 (K), D28.1 (K), D29.1 (K), D30.1 (K), D31.1 (K), D32.1 (K), D33.1 (K), D34.1 (K), D35.1 (K), D36.1 (K), U1.11 (8/PB4)
ROW3: D37.1 (K), D38.1 (K), D39.1 (K), D40.1 (K), D41.1 (K), D42.1 (K), U1.13 (10/PB6)

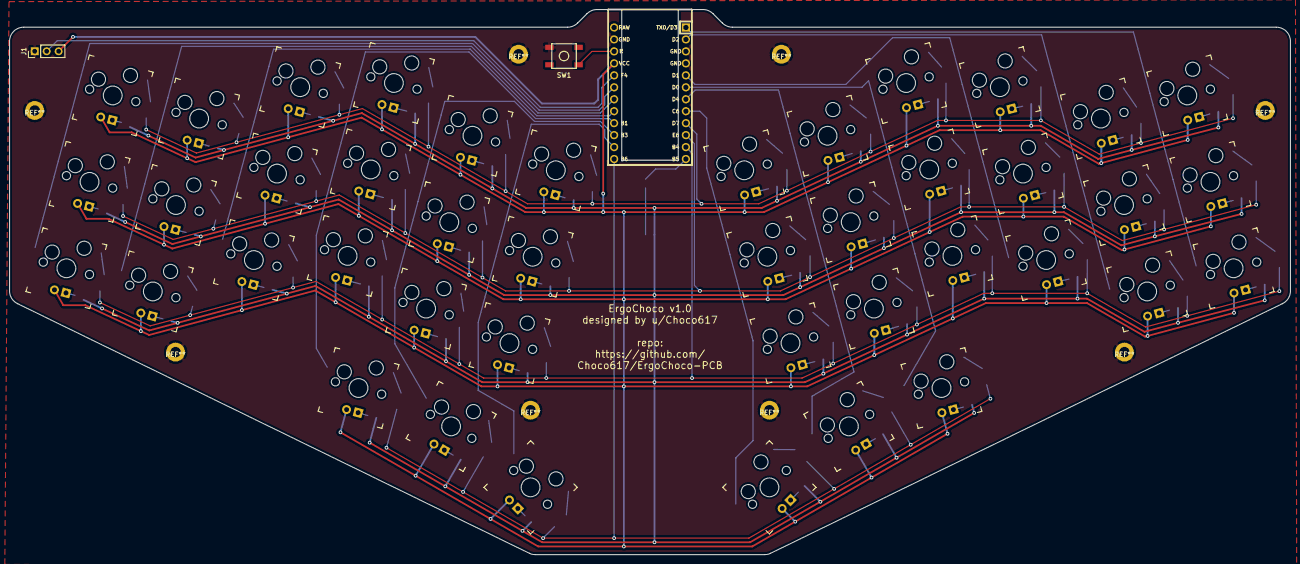
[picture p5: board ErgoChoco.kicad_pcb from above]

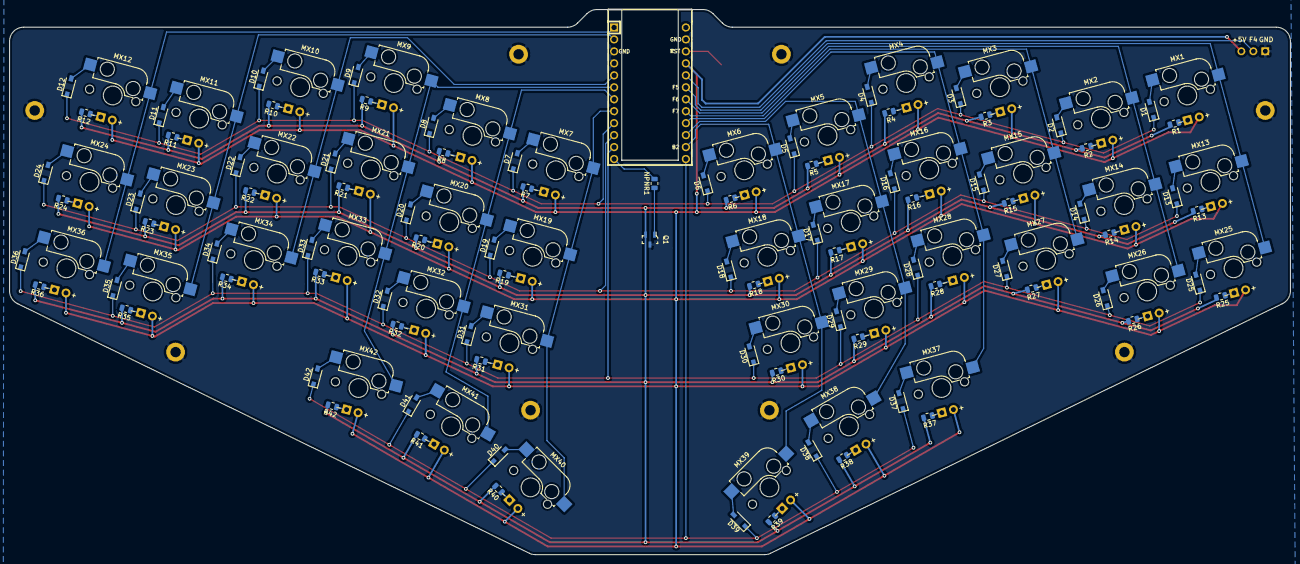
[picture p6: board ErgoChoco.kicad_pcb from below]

Board: 2 copper layers, 272.0 x 115.8 mm, 131 parts (87 on the bottom side), 107 nets.

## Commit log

2020-06-16 initialize KiCAD project
    literally just making a new blank project
    [Corneus.kicad_pcb, Corneus.sch]
2020-06-16 schematic done-ish
    still to do (at least):
    assign real reference designators to everything (number switches, diodes, resistors, etc.)
    assign rows/columns to specific pins on the atmega32u4 (will do this based on convenient routing in the pcb layout, so I don't know yet)
    add something for ESD protection probably
    probably some other stuff I haven't thought of yet
2020-06-16 LED PWM
    immediately thought of a schematic update to make: LED PWM
    [Corneus.sch]
2020-06-16 USB resistors
    another schematic update to add resistors to USB D+/-
    [Corneus.sch]
2020-06-16 add daprice submodule for Kailh hotswap reference footprint
2020-06-18 created footprints
    new footprints combining Kailh hotswap sockets and LEDs
2020-06-18 added PCB mount holes to custom footprints
2020-06-19 assigned reference designators
    [Corneus.sch]
2020-06-19 add Digi-Key KiCad library for micro USB footprint
2020-06-19 add manufacturer USB footprint, renumber resistors
    Realized I had R1-R6 but also my LED resistors were numbered in sync with the switches, so 1-6 were doubled up. Renumbered 1-6 to 43-48. Also, I found that the micro USB port manufacturer offers thei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
    [Corneus.sch]
2020-06-19 added ESD
    added ESD IC used in Masterzen's PCB design guide, the CPM43, and the Voyager40
    [Corneus.sch]
2020-06-20 remove redundant USB resistors, add submodule for JLCPCB design rules
    [Corneus.kicad_pcb, Corneus.sch, CorneusBOM.csv]
2020-06-20 PCB layout setup
    imported JLCPCB design rules from sethhillbrand, set some settings per ai03's guide, about to import everything and start doing layout
    [Corneus.kicad_pcb]
2020-06-20 imported schematic and vaguely located switches
    [Corneus.kicad_pcb]
2020-06-20 vaguely located MCU related components
    [Corneus.kicad_pcb]
2020-06-21 precisely located all switches
    switches, diodes, and LED resistors located by coordinates generated from mechanical CAD layout
    [Corneus.kicad_pcb]
2020-06-22 MCU components better placed
    moved MCU components around atmega32u4 as needed, moved whole group to center, moved MOSFET to right hand gap under period, moved reset switch to left hand under X
    [Corneus.kicad_pcb]
2020-06-22 added edge cuts
    -corrected layer settings
    -made net class settings
    -added edge cuts
    -located MCU components pretty precisely
    -located micro USB precisely
    -started routing
    [Corneus.kicad_pcb]
2020-06-23 more MCU routing
    [Corneus.kicad_pcb]
2020-06-23 routed all switches to their diodes
    also some column 0 stuff
    [Corneus.kicad_pcb]
2020-06-23 routed switch rows and columns
    [Corneus.kicad_pcb]
2020-06-24 routed LEDGND and the missed bottom switch row
    [Corneus.kicad_pcb]
2020-06-24 routed more LED stuff
    -routed LED +5V
    -removed unnecessary traces between hands (just because I relied on LED rows in the handwire doesn't mean I have to on this PCB)
    -routed all LEDs to their respective resistors
    [Corneus.kicad_pcb]
2020-06-25 replaced MOSFET footprint, started routing right hand columns
    [Corneus.kicad_pcb]
2020-06-28 routed rows and columns
    [Corneus.kicad_pcb, Corneus.sch]
2020-06-28 added mounting holes
    [Corneus.kicad_pcb]
2020-06-28 routed decoupling capacitors 5V
    -also swapped 10uF cap with one of the 0.1uF ones to put the 10 in the correct place
    -about to rotate the whole MCU region 180 degrees to correct a USB routing sin, this is going to involve rerouting all the row/column connections to the MCU but probably result in tidier traces overall
    [Corneus.kicad_pcb]
2020-06-28 rotated MCU region and routed rows
    [Corneus.kicad_pcb, Corneus.sch]
2020-07-04 rerouted columns
    [Corneus.kicad_pcb, Corneus.sch]
2020-07-05 add ground fills, adjust some traces to improve clearance
    [Corneus.kicad_pcb, Corneus.sch]
2020-07-05 added tooling holes
    [Corneus.kicad_pcb]
2020-07-05 added name/rev/repo details on silkscreen layer
    [Corneus.kicad_pcb]
2020-07-05 renamed KiCad project from Corneus to ErgoChoco
    [ErgoChoco.kicad_pcb, ErgoChoco.sch, ErgoChocoBOM.csv]
2020-07-05 update titleblocks on schematic and pcb layout
    -license updated from MIT to CC BY-NC
    -project name updated in titleblock
    -date updated to 7.5.20
    [ErgoChoco.kicad_pcb, ErgoChoco.sch]
2020-07-13 late updates before asking Reddit for help
    -remove tooling holes again
    -rename BOM and add JLCPCB BOM + CPL
    -update readme to include layout explanation
    -add gerbers
    [ErgoChoco-Edge_Cuts.dxf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]
2020-07-13 add schematic PCB, update readme, remove DXFs
    [ErgoChoco-Edge_Cuts.dxf]
2020-07-13 started deleting things from integrated MCU
    -deleted traces and edge cuts in pcbnew
    [ErgoChoco.kicad_pcb]
2020-07-13 deleted old schematic for atmega32u4 also
    [ErgoChoco.sch]
2020-07-13 Add Keebio schematic symbols
2020-07-13 introduced Pro Micro
    -put Pro Micro into schematic
    -updated PCB from schematic
    -moved all switches 10mm farther apart
    [ErgoChoco.kicad_pcb, ErgoChoco.sch]
2020-07-14 routed columns
    -routed columns together (not to Pro Micro yet)
    -flipped diodes and resistors to back side of board
    -added calculator for figuring out weird angles of traces
    [ErgoChoco.kicad_pcb, angled trace calculator.xls]
2020-07-14 routed LH top row
    [ErgoChoco.kicad_pcb, angled trace calculator.xls]
2020-07-15 routed other two LH rows
    -still excluding innermost row and thumb cluster for now
    [ErgoChoco.kicad_pcb, ErgoChoco.sch, angled trace calculator.xls]
2020-07-16 routed right hand and thumb arcs
    -still haven't routed innermost column on left hand
    -need to establish Pro Micro location and edge cuts first
    [ErgoChoco.kicad_pcb, angled trace calculator.xls]
2020-07-16 added edge cuts, located PM
    [ErgoChoco.kicad_pcb]
2020-07-26 finished routing, added mounting holes
    [ErgoChoco-Edge_Cuts.dxf, ErgoChoco-F_Cu.dxf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]
2021-10-30 update README to link to case repo
    [ErgoChoco.csv]
2021-11-22 updated BOM csvs for Pro Micro version
    -deleted JLCPCB csvs
    -revised detailed BOM to show components I actually used
    [ErgoChocoBOM-JLCPCB.csv, ErgoChocoBOM-detailed.csv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]
